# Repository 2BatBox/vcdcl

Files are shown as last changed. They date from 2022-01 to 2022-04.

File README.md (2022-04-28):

# Voltage-controlled direct current load.

## Operating conditions
Supply Voltage +19.5(+-2)V  
Load voltage (protected input) -200V to +55V  
Load voltage (unprotected input) 0 to +55V  
Load current (both inputs) 10A  
Load power (continuous) 100W  
Input voltage range 0-10V  
Input frequency (at full input voltage range) 0-2kHz  

## Schematics.
main_board

supply_board

## The first prototype.

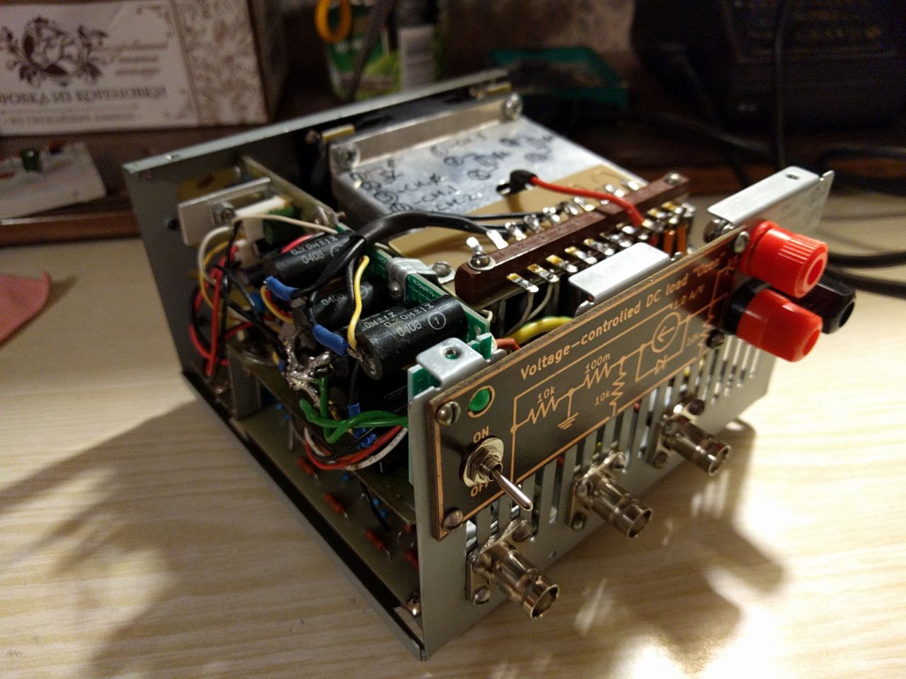
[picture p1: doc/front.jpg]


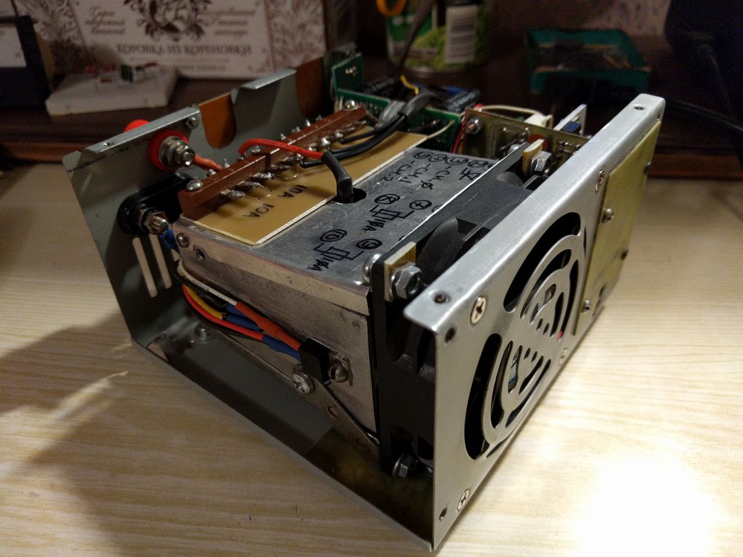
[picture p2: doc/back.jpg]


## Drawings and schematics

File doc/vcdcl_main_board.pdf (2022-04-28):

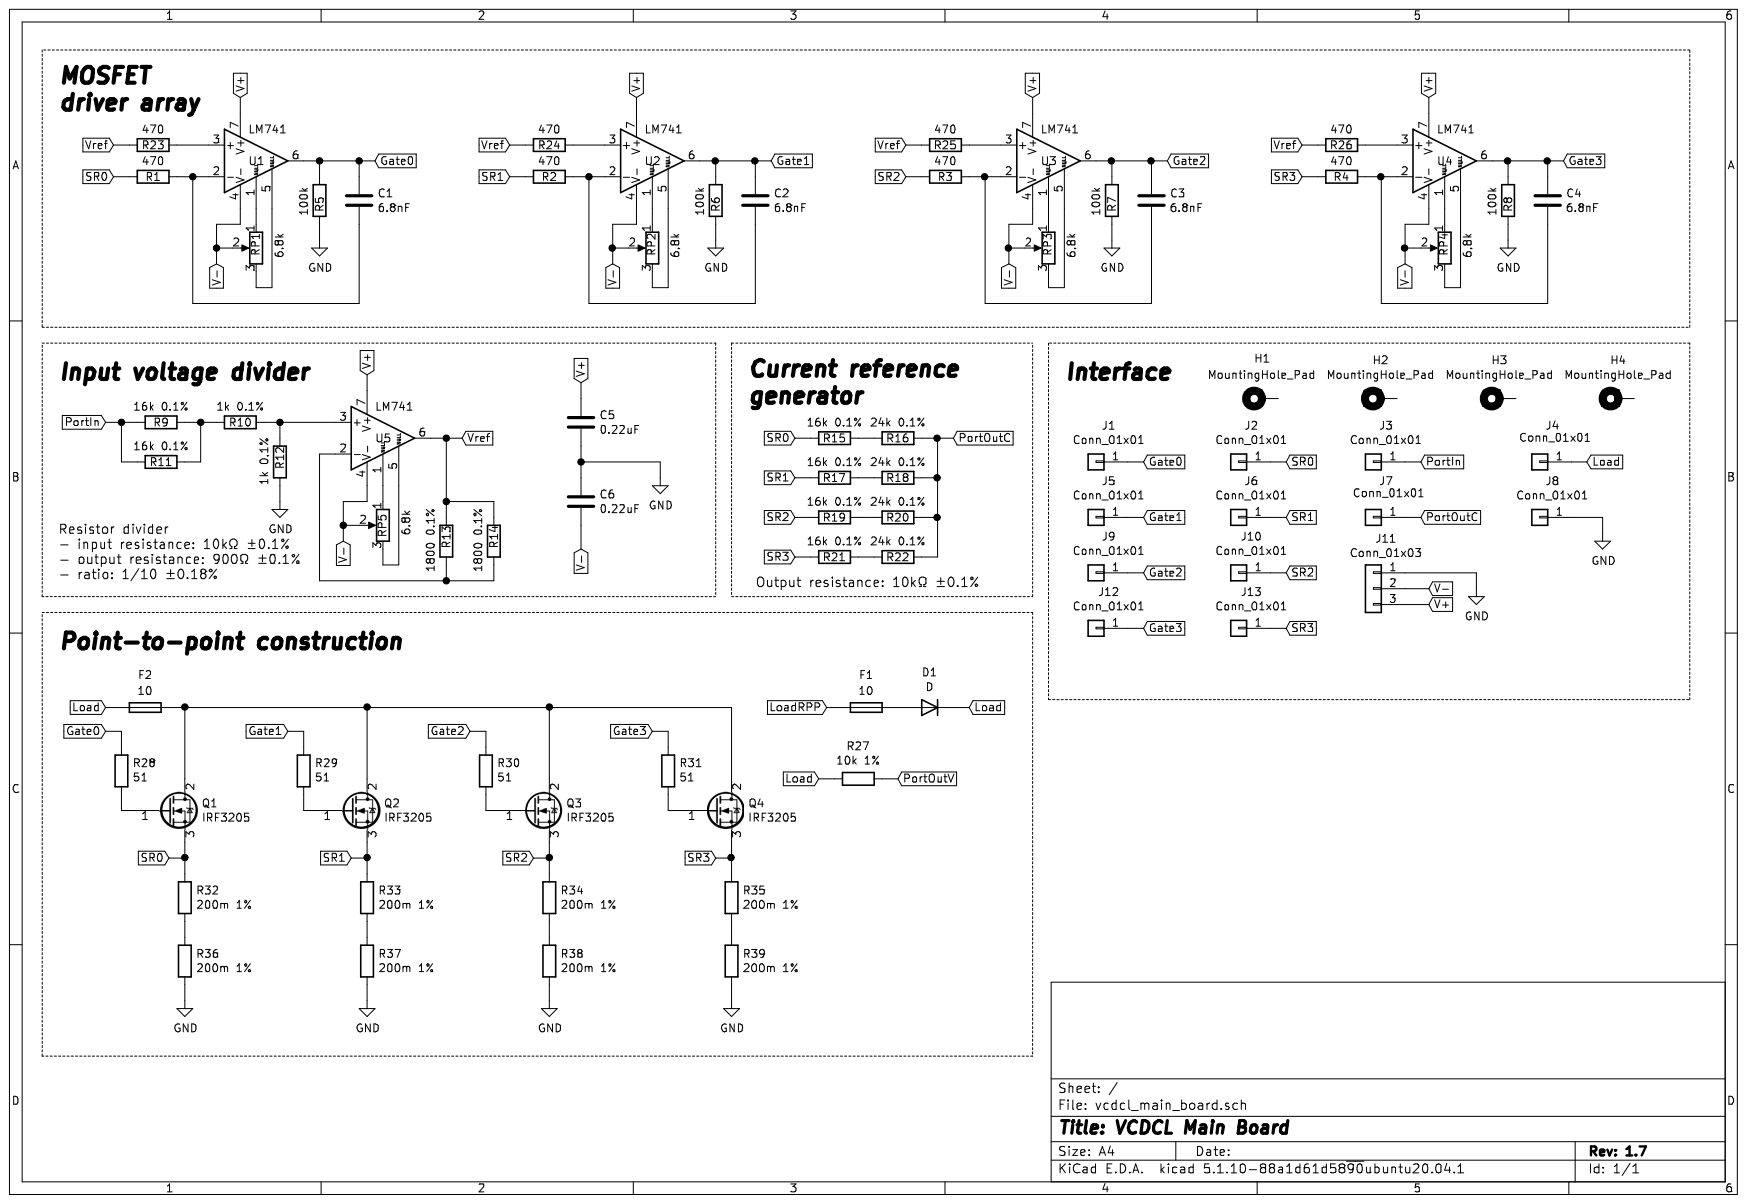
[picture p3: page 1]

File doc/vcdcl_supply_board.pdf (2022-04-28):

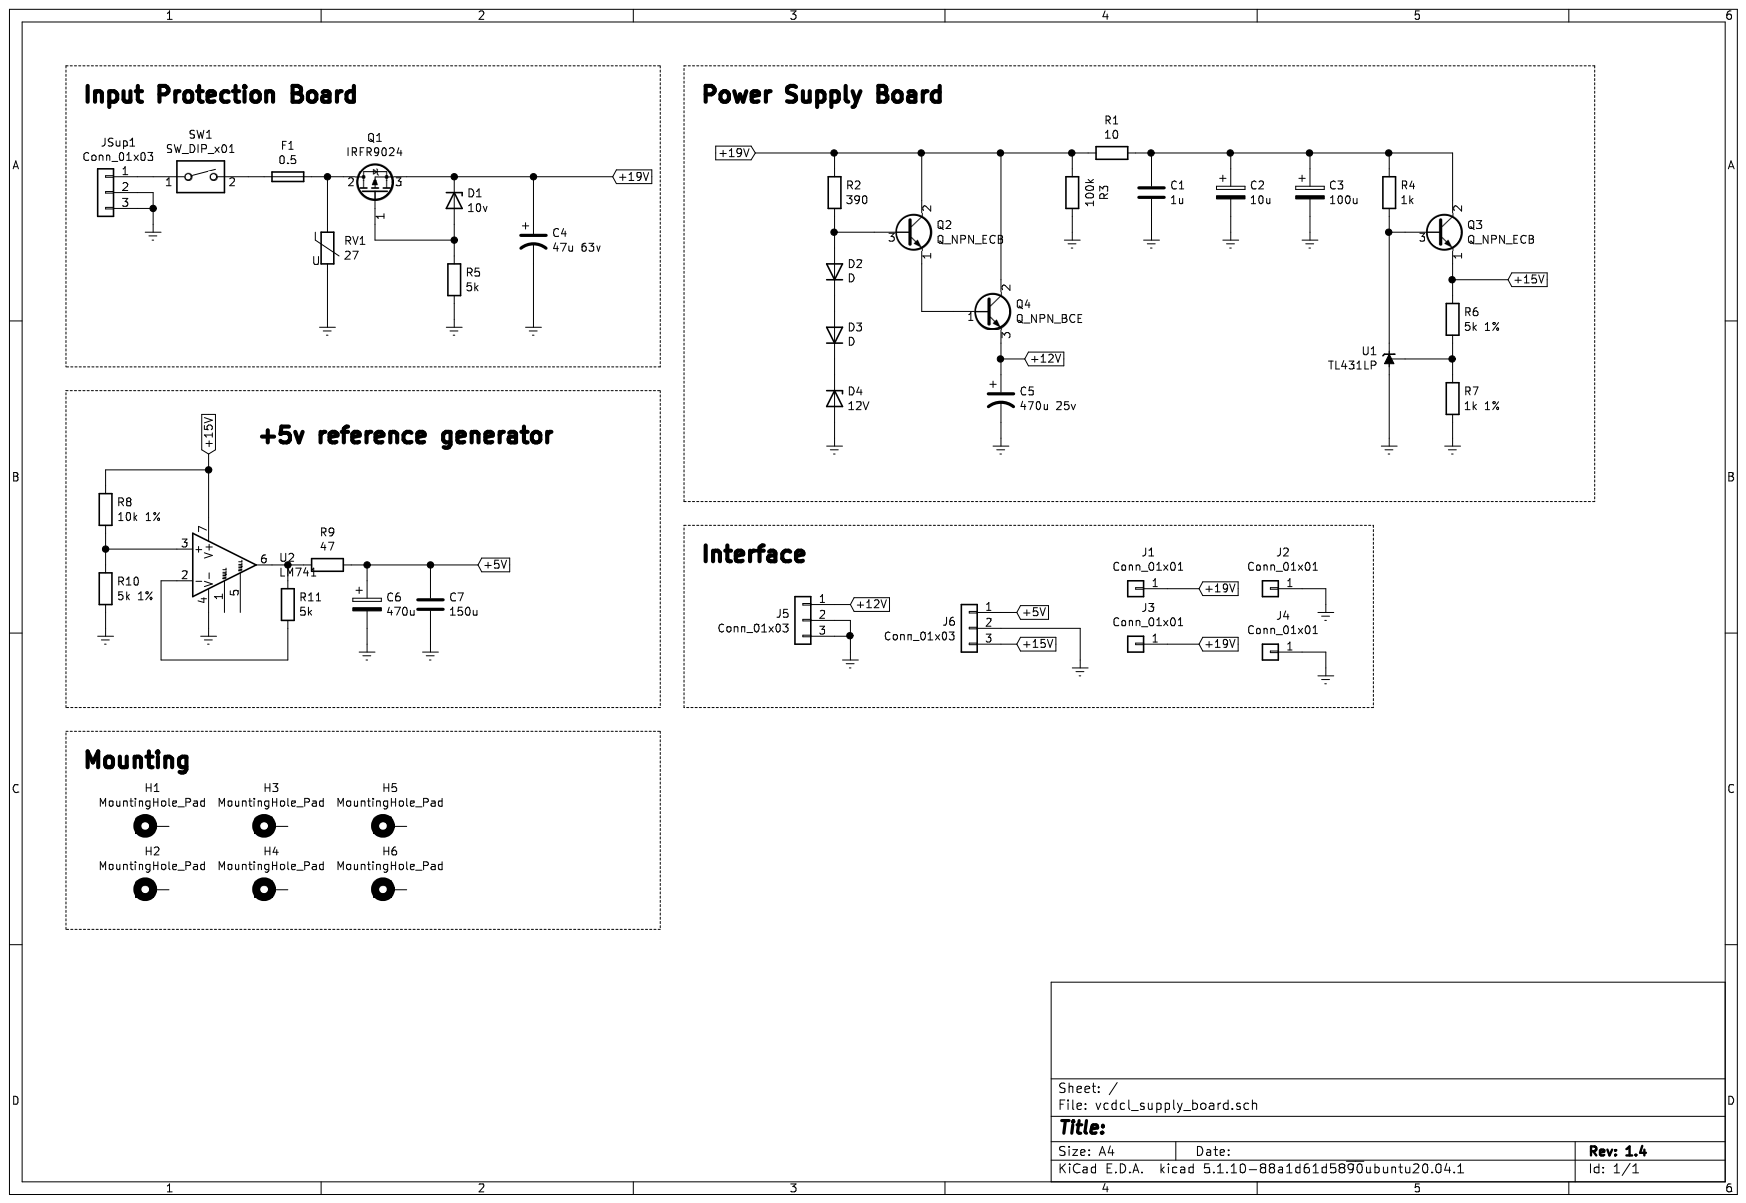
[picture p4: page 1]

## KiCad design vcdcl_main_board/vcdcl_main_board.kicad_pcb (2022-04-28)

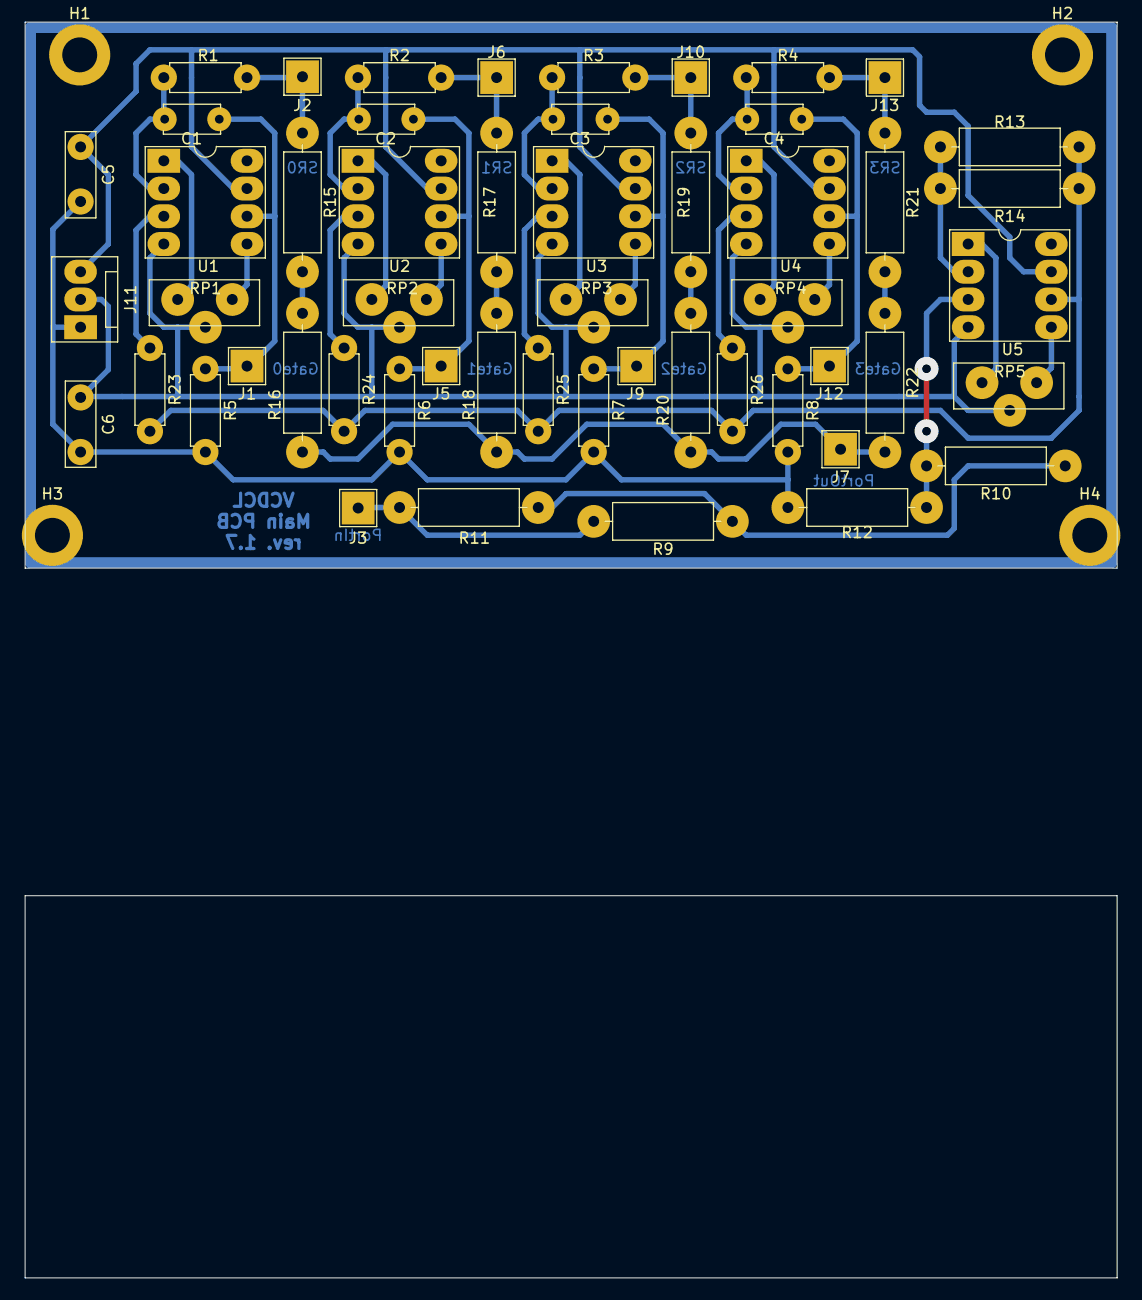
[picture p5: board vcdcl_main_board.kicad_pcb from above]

Board: 2 copper layers, 100.0 x 50.0 mm, 57 parts (0 on the bottom side), 39 nets.

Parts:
C1, C2, C3, C4: 6.8nF; LUT_C_Disc_D5.0mm_W2.5mm_P5.00mm
C5, C6: 0.22uF; LUT_C_Rect_H7.0mm_W2.0mm_P5.00mm
H1, H2, H3, H4: MountingHole_Pad; MountingHole_3.2mm_M3_DIN965_Pad
J1, J2, J3, J5, J6, J7, J9, J10, J12, J13: Conn_01x01; LUT_PinHeader_1x01_P2.54mm_Vertical
J11: Conn_01x03; LUT_FanPinHeader_1x03_P2.54mm_Vertical
R1, R2, R3, R4, R23, R24, R25, R26: 470; LUT_R_L6.3mm_D2.5mm_P7.62mm_Horizontal
R5, R6, R7, R8: 100k; LUT_R_L6.3mm_D2.5mm_P7.62mm_Horizontal
R9, R11, R15, R17, R19, R21: 16k 0.1%; LUT_R_L9.0mm_D3.2mm_P12.70mm_Horizontal
R10, R12: 1k 0.1%; LUT_R_L9.0mm_D3.2mm_P12.70mm_Horizontal
R13, R14: 1800 0.1%; LUT_R_L9.0mm_D3.2mm_P12.70mm_Horizontal
R16, R18, R20, R22: 24k 0.1%; LUT_R_L9.0mm_D3.2mm_P12.70mm_Horizontal
RP1, RP2, RP3, RP4, RP5: 6.8k; LUT_Potentiometer_SP3_Vertical
U1, U2, U3, U4, U5: LM741; LUT_DIP-8

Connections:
GND: C5.2, C6.1, J11.1, R5.2, R6.2, R7.2, R8.2, R12.2
Gate0: C1.1, J1.1, R5.1, U1.6
Gate1: C2.1, J5.1, R6.1, U2.6
Gate2: C3.1, J9.1, R7.1, U3.6
Gate3: C4.1, J12.1, R8.1, U4.6
unnamed: C1.2, R1.1, U1.2
unnamed: C2.2, R2.1, U2.2
unnamed: C3.2, R3.1, U3.2
unnamed: C4.2, R4.1, U4.2
unnamed: R10.1, R12.1, U5.3
unnamed: R9.1, R10.2, R11.1
unnamed: R13.2, R14.2, U5.2
unnamed: R15.1, R16.2
unnamed: R17.1, R18.2
unnamed: R19.1, R20.2
unnamed: R21.1, R22.2
unnamed: R23.1, U1.3
unnamed: R24.1, U2.3
unnamed: R25.1, U3.3
unnamed: R26.1, U4.3
unnamed: RP1.1, U1.1
unnamed: RP1.3, U1.5
unnamed: RP2.1, U2.1
unnamed: RP2.3, U2.5
unnamed: RP3.1, U3.1
unnamed: RP3.3, U3.5
unnamed: RP4.1, U4.1
unnamed: RP4.3, U4.5
unnamed: RP5.1, U5.1
unnamed: RP5.3, U5.5
PortIn: J3.1, R9.2, R11.2
PortOutC: J7.1, R16.1, R18.1, R20.1, R22.1
SR0: J2.1, R1.2, R15.2
SR1: J6.1, R2.2, R17.2
SR2: J10.1, R3.2, R19.2
SR3: J13.1, R4.2, R21.2
V+: C5.1, J11.3, U1.7, U2.7, U3.7, U4.7, U5.7
V-: C6.2, J11.2, RP1.2, RP2.2, RP3.2, RP4.2, RP5.2, U1.4, U2.4, U3.4, U4.4, U5.4
Vref: R13.1, R14.1, R23.2, R24.2, R25.2, R26.2, U5.6

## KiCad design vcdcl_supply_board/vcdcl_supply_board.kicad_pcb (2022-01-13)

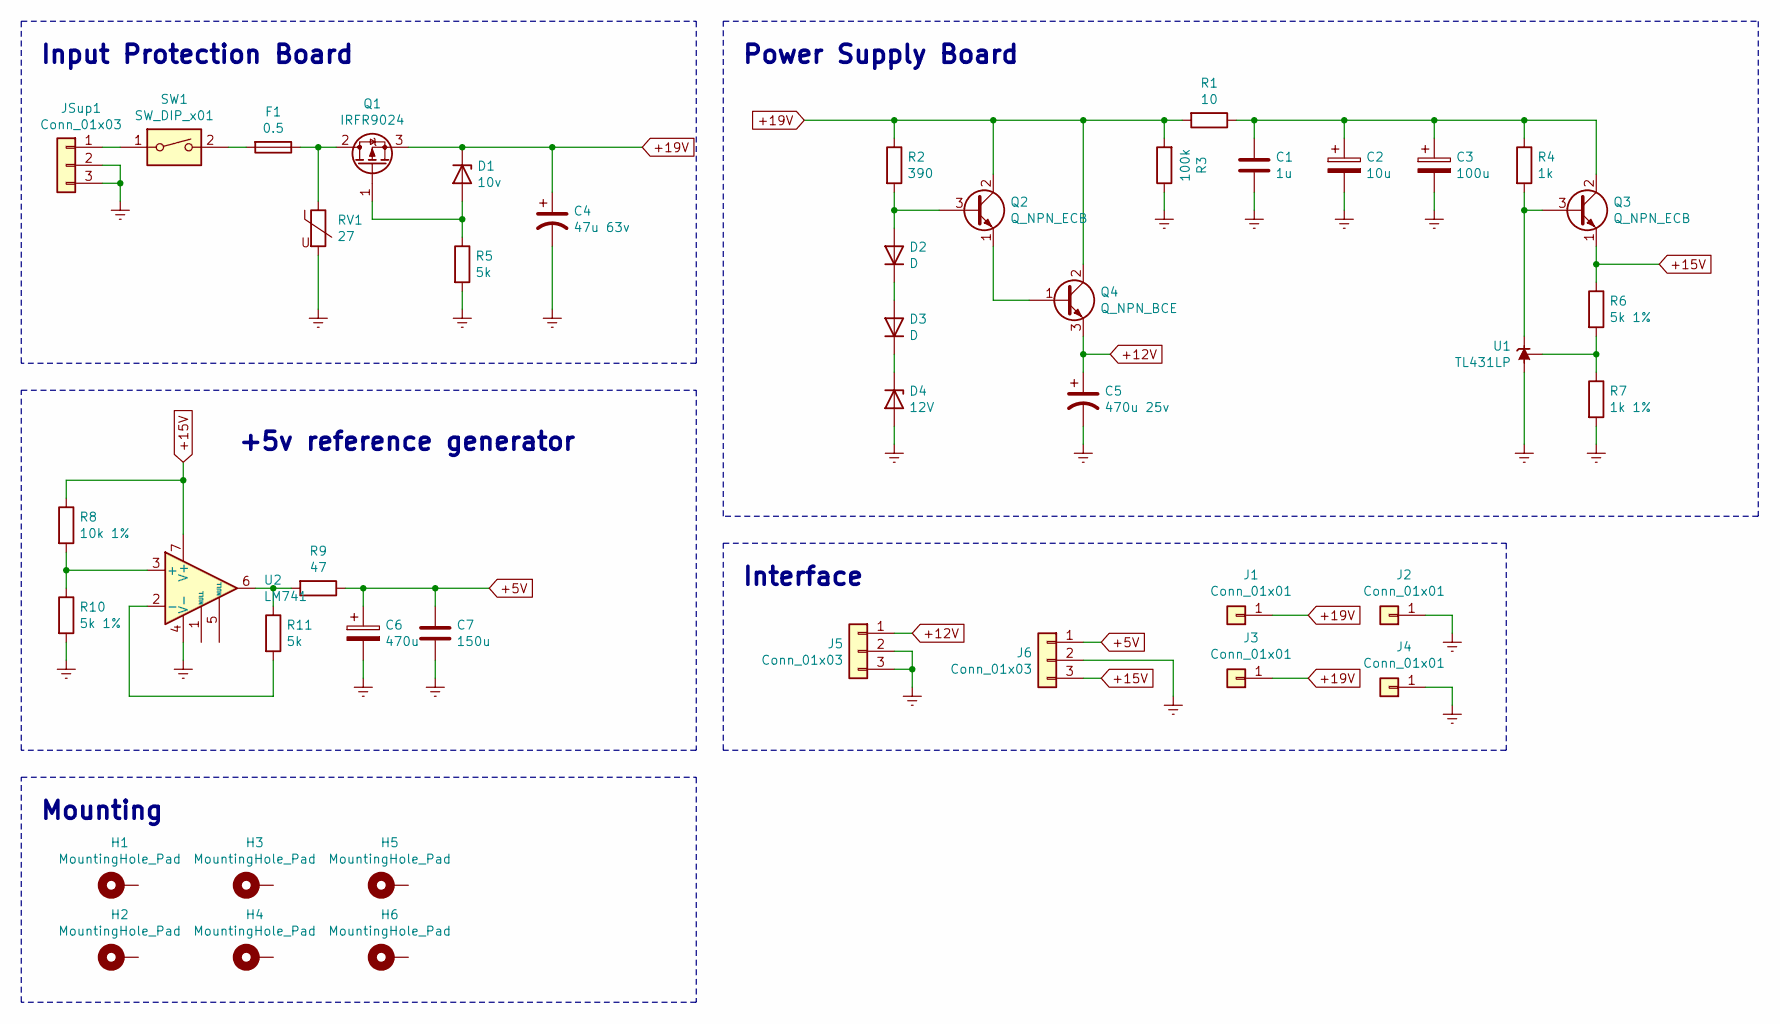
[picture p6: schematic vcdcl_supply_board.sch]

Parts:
C1: 1u; LUT_C_Rect_L7.0mm_W4.5mm_P5.00mm
C2: 10u; LUT_CP_Radial_D4.0mm_P2.00mm
C3: 100u; LUT_CP_Radial_D6.3mm_P2.50mm
C4: 47u 63v; LUT_CP_Radial_D8.0mm_P2.50mm
C5: 470u 25v; LUT_CP_Radial_D6.3mm_P2.50mm
C6: 470u; LUT_CP_Radial_D6.3mm_P2.50mm
C7: 150u; LUT_C_Rect_L10.3mm_W5.0mm_P7.50mm
D1: 10v; LUT_D_P10.16mm_Horizontal
D2, D3: D; LUT_D_P7.62mm_Horizontal
D4: 12V; LUT_D_P10.16mm_Horizontal
F1: 0.5; LUT_Fuse-5x20mm_Horizontal_Open
H1, H2, H3, H4, H5, H6: MountingHole_Pad; MountingHole_3.2mm_M3_ISO7380_Pad
J1, J2, J3, J4: Conn_01x01; LUT_PinHeader_1x01_P2.54mm_Vertical
J5, J6: Conn_01x03; LUT_FanPinHeader_1x03_P2.54mm_Vertical
JSup1: Conn_01x03; LUT_BarrelJack_Horizontal
Q1: IRFR9024; LUT_TO-251-3_Vertical
Q2, Q3: Q_NPN_ECB; LUT_TO-92
Q4: Q_NPN_BCE; LUT_TO-220-3_Vertical
R1: 10; LUT_R_L6.3mm_D2.5mm_P7.62mm_Horizontal
R2: 390; LUT_R_L6.3mm_D2.5mm_P7.62mm_Horizontal
R3: 100k; LUT_R_L6.3mm_D2.5mm_P7.62mm_Horizontal
R4: 1k; LUT_R_L6.3mm_D2.5mm_P7.62mm_Horizontal
R5, R11: 5k; LUT_R_L6.3mm_D2.5mm_P7.62mm_Horizontal
R6, R10: 5k 1%; LUT_R_L6.3mm_D2.5mm_P7.62mm_Horizontal
R7: 1k 1%; LUT_R_L6.3mm_D2.5mm_P7.62mm_Horizontal
R8: 10k 1%; LUT_R_L6.3mm_D2.5mm_P7.62mm_Horizontal
R9: 47; LUT_R_L6.3mm_D2.5mm_P7.62mm_Horizontal
RV1: 27; LUT_R_L9.0mm_D3.2mm_P5.08mm_Vertical
SW1: SW_DIP_x01; LUT_PinHeader_1x02_P2.54mm_Vertical
U1: TL431LP; LUT_TO-92
U2: LM741; LUT_DIP-8

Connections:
+5V: C6.1, C7.1, J6.1, R9.1
+12V: C5.1, J5.1, Q4.3 (E)
+15V: J6.3, Q3.1 (E), R6.1, R8.1, U2.7 (V+)
+19V: C4.1, D1.1 (K), J1.1, J3.1, Q1.3 (S), Q2.2 (C), Q4.2 (C), R1.2, R2.1, R3.2
Earth: C1.2, C2.2, C3.2, C4.2, C5.2, C6.2, C7.2, D4.2 (A), J2.1, J4.1, J5.2, J5.3, J6.2, JSup1.2, JSup1.3, R3.1, R5.2, R7.2, R10.2, RV1.2, U1.2 (A), U2.4 (V-)
unnamed: C1.1, C2.1, C3.1, Q3.2 (C), R1.1, R4.1
unnamed: D1.2 (A), Q1.1 (G), R5.1
unnamed: D2.1 (K), D3.2 (A)
unnamed: D2.2 (A), Q2.3 (B), R2.2
unnamed: D3.1 (K), D4.1 (K)
unnamed: F1.1, Q1.2 (D), RV1.1
unnamed: F1.2, SW1.2
unnamed: JSup1.1, SW1.1
unnamed: Q2.1 (E), Q4.1 (B)
unnamed: Q3.3 (B), R4.2, U1.3 (K)
unnamed: R6.2, R7.1, U1.1 (REF)
unnamed: R8.2, R10.1, U2.3 (+)
unnamed: R9.2, R11.1, U2.6
unnamed: R11.2, U2.2 (-)

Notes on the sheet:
Input Protection Board
+5v reference generator
Power Supply Board
Interface
Mounting

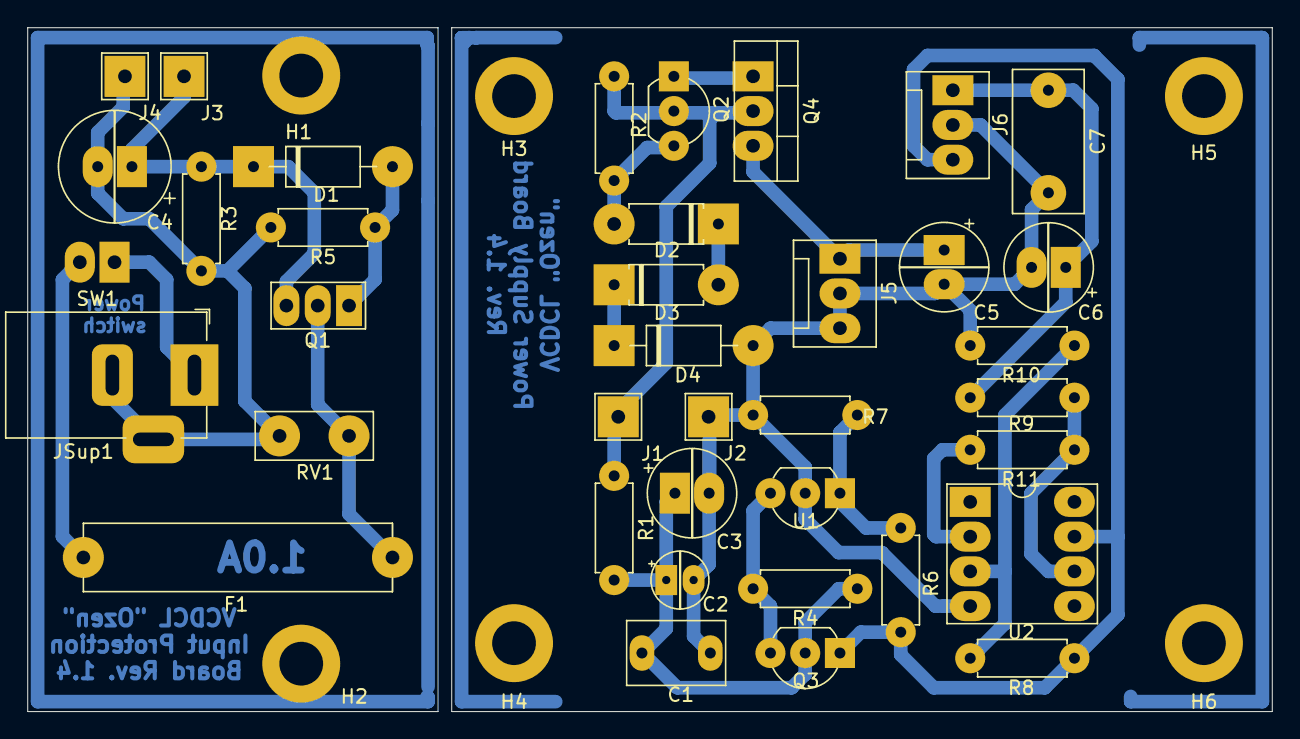
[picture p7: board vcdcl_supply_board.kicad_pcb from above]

Board: 2 copper layers, 91.0 x 50.0 mm, 44 parts (0 on the bottom side), 19 nets.

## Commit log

2021-12-16 Update supply board
2021-12-16 Append prototype photo
2022-01-06 Supply board fixes
    [vcdcl_supply_board.kicad_pcb, vcdcl_supply_board.sch]
2022-01-13 Both boards update
    [vcdcl_main_board.kicad_pcb, vcdcl_main_board.sch, vcdcl_supply_board.kicad_pcb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]
2022-04-28 Append schematic pdf files
    [vcdcl_main_board.kicad_pcb]
